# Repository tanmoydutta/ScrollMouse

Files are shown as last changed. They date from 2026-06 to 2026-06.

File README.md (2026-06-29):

# Scroll Mouse using manetic angle sensor
A BLE mouse dial for smooth and minimum effort scrolling. 

Powered by nRF52840 BLE Soc, this HID input device is to reduce effort in scrolling. 

## Demo

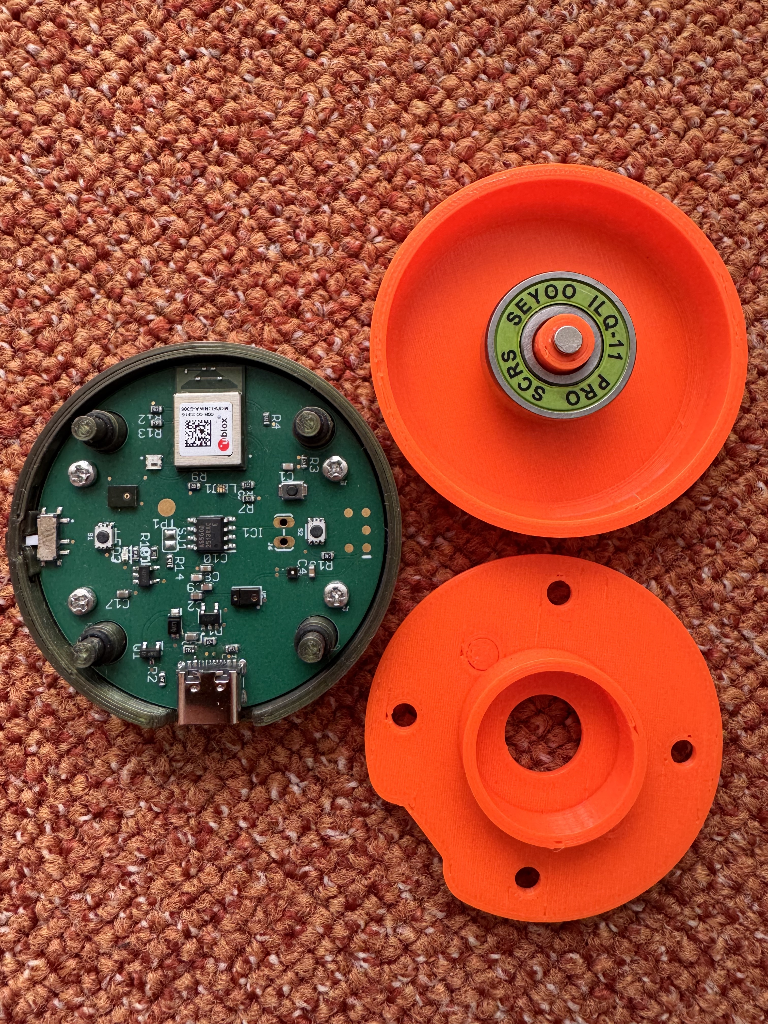
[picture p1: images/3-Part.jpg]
Watch the Scroll Mouse demo


_Click the image to watch the video._

Here is an open view of the device - 


Here is a complete 3D view of the device - 
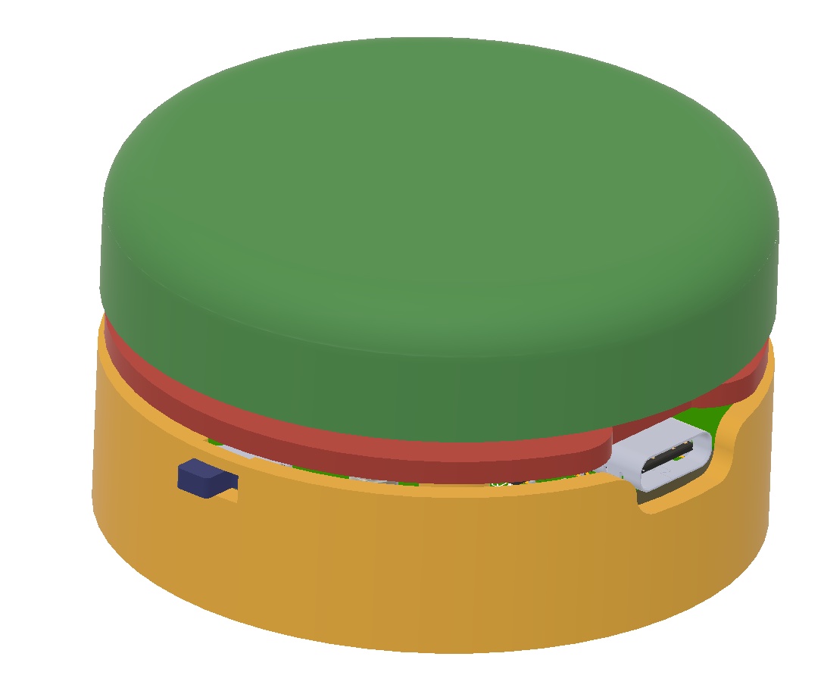
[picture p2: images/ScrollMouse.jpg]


The PCB is designed around AS5600 mangetic engle encoder- 
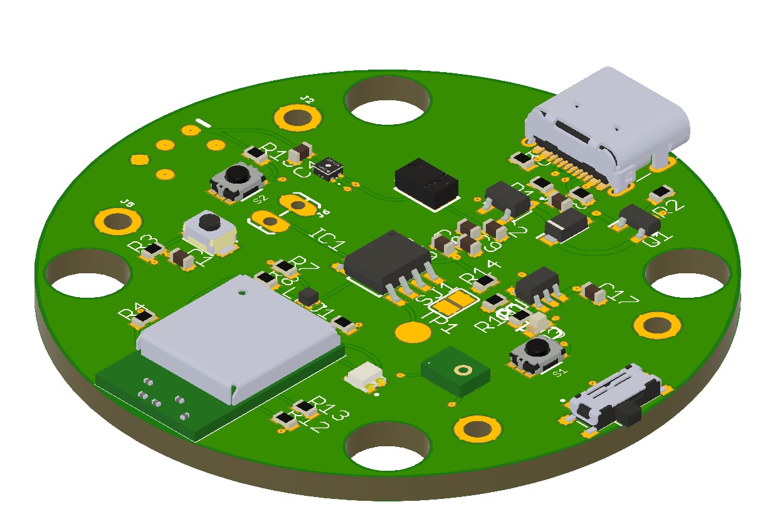
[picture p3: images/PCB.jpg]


In the center is a 608 2RS Bearing for long boards making the swivel action smooth and long running -
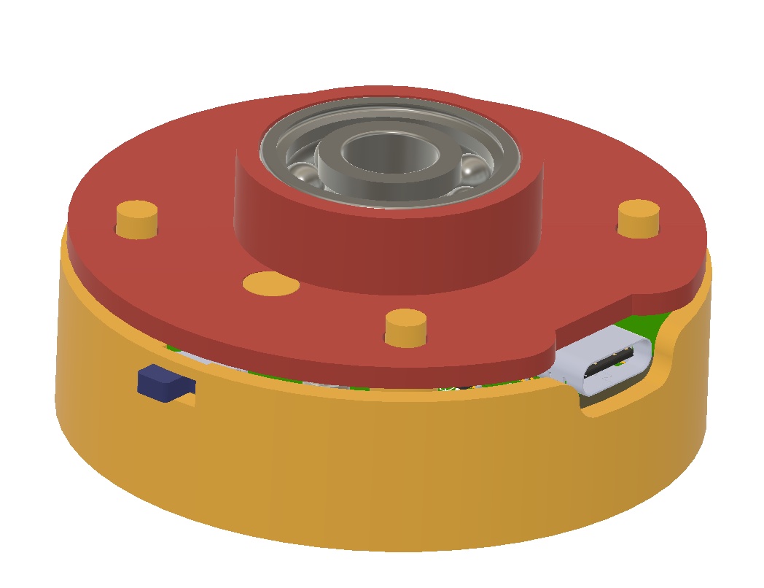
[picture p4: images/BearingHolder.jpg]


The radial magnet in the center of the bearing floats on top of the AS5600 sensor chip to detect the angle of rotation -
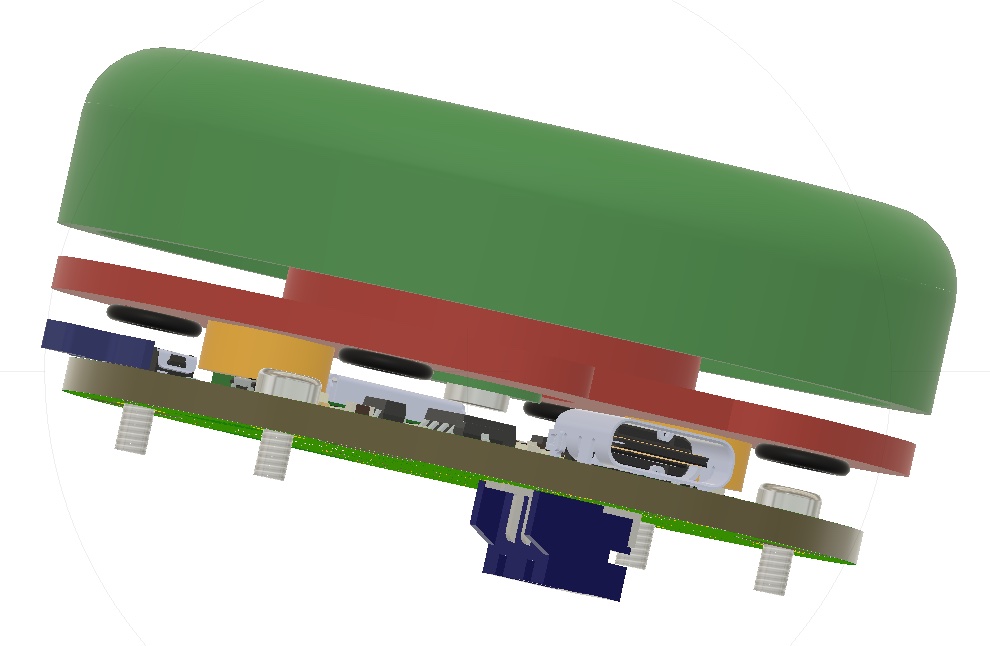
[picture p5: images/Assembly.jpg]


The diametrically magnetised permanent magnet sits in the center of the dial assembly - 
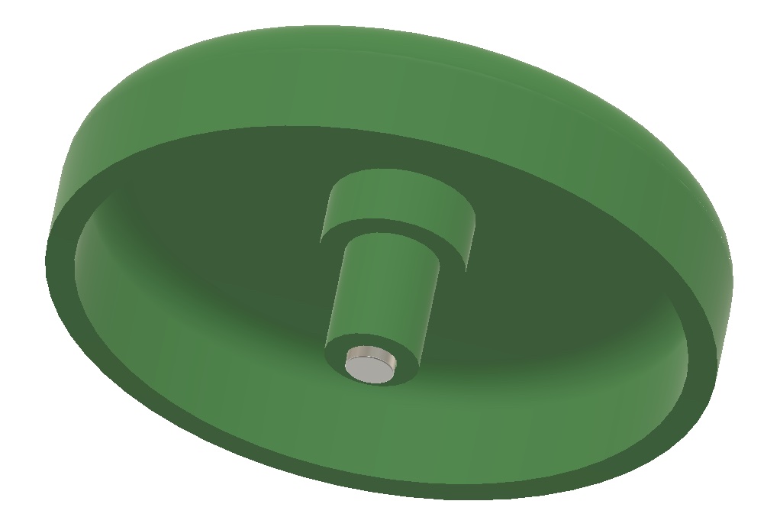
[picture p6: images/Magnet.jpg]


This project is certified as Open Source Hardware - 
<p align="center">
  <a href="https://certification.oshwa.org/nl000044.html">
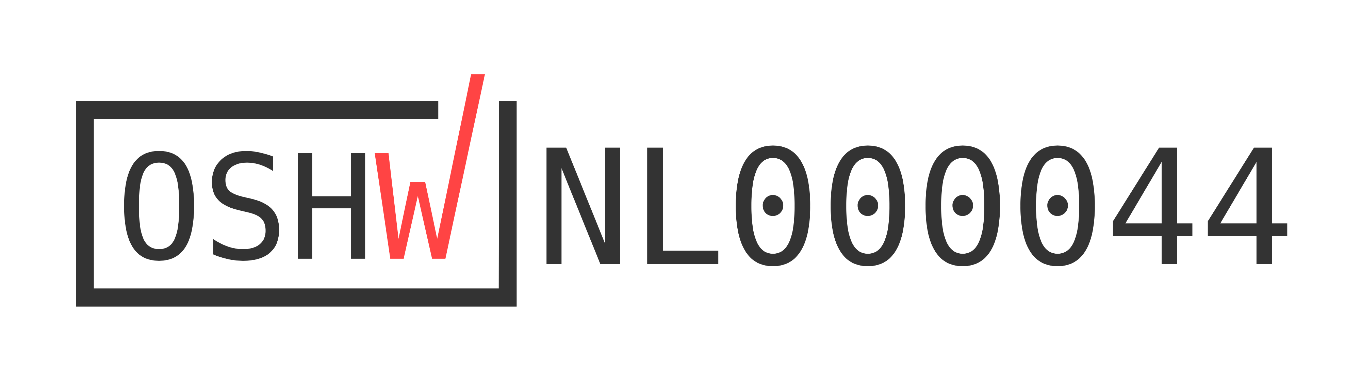
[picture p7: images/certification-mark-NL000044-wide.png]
OSHWA OSHWA Certification
    
  </a>
</p>



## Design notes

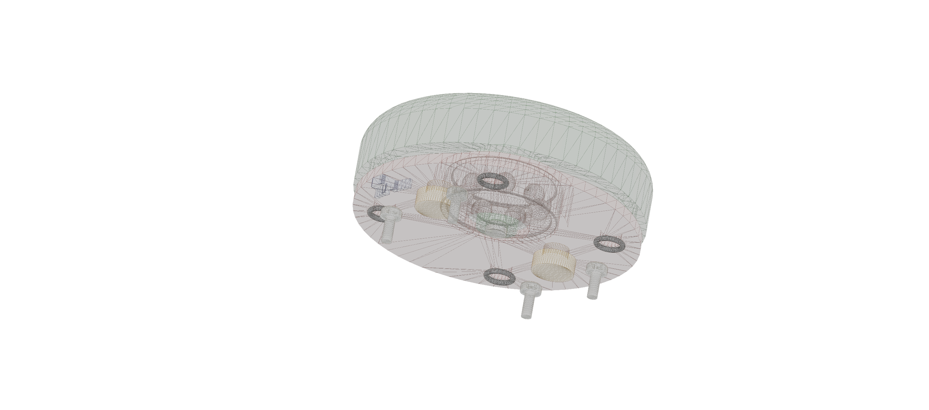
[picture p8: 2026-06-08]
images/ScrollMouseMechanical.png

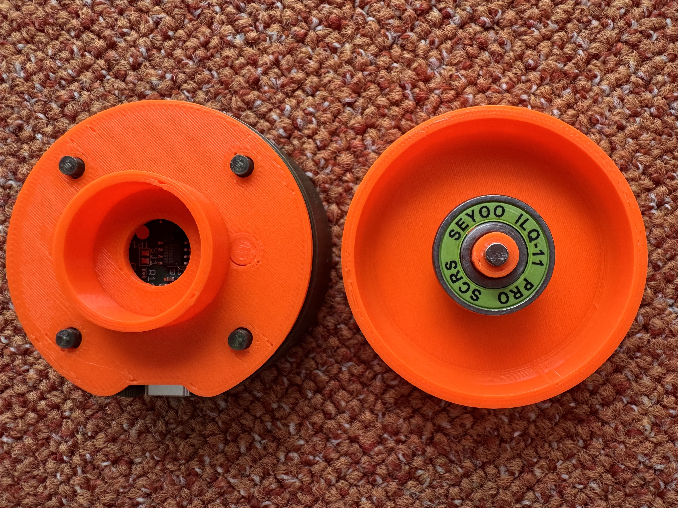
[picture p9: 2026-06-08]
images/2-Part.jpg

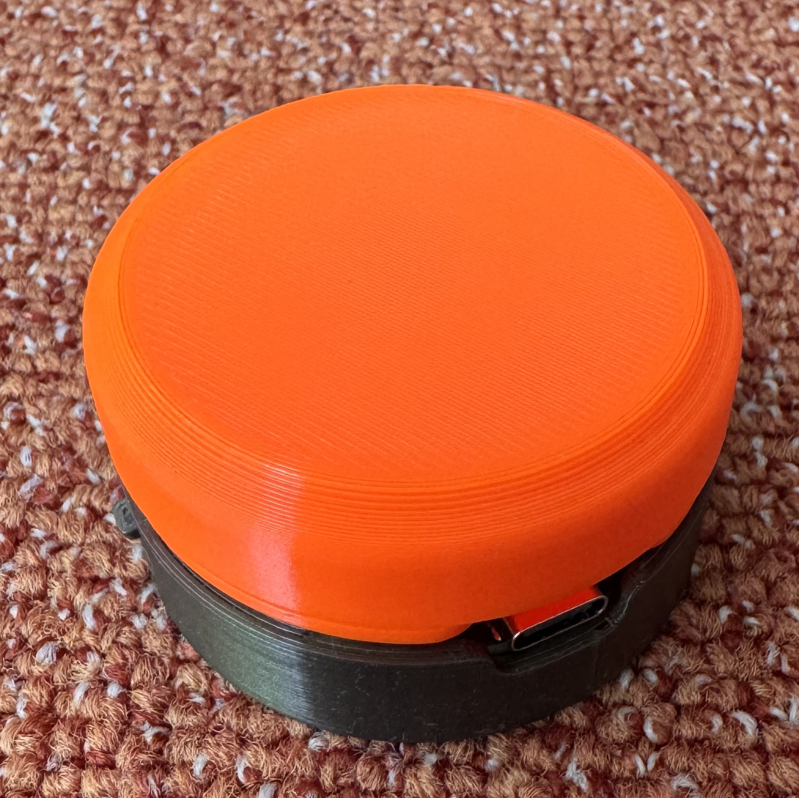
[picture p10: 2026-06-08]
images/Burger.jpg

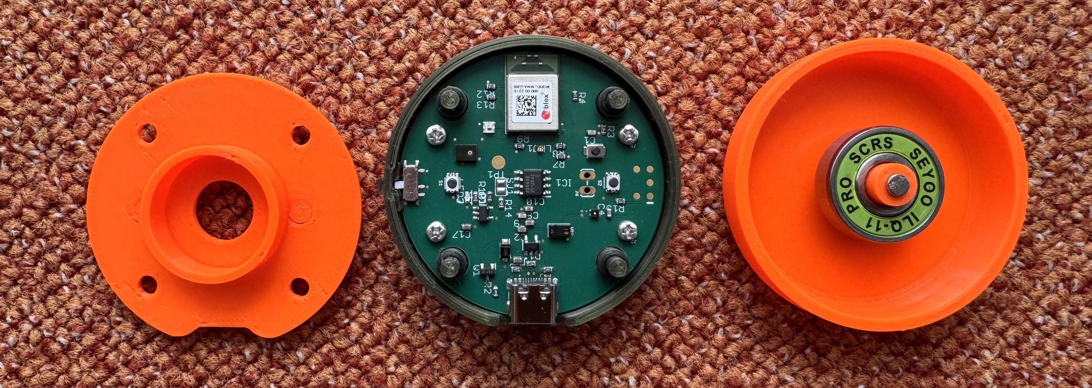
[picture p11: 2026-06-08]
images/Stator-Rotor-Holder-Sensor.jpg

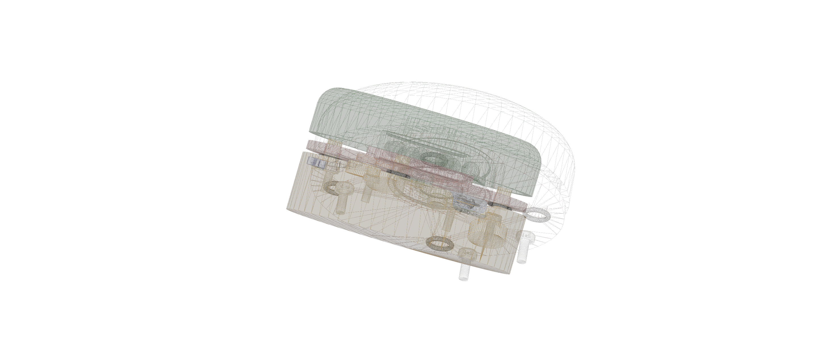
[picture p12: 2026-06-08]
images/ScrollMouse3D.png

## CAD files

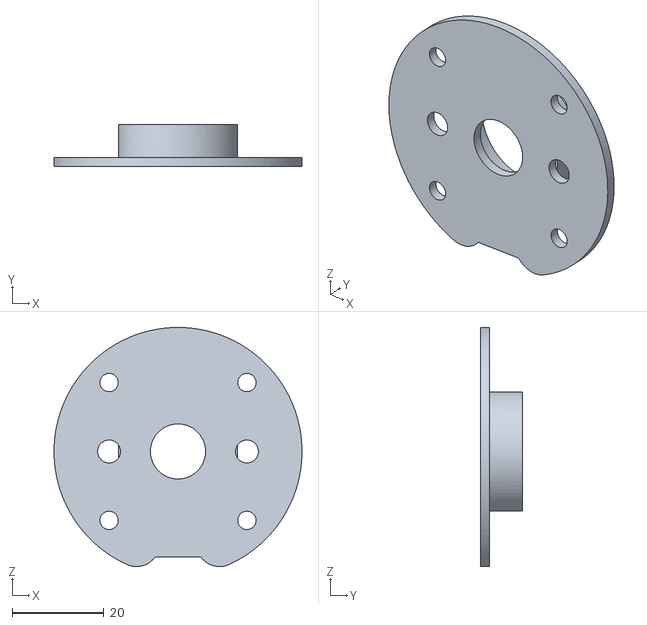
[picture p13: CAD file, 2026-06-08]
3D/BearingHolder.stl
54.0 x 9.20 x 52.1

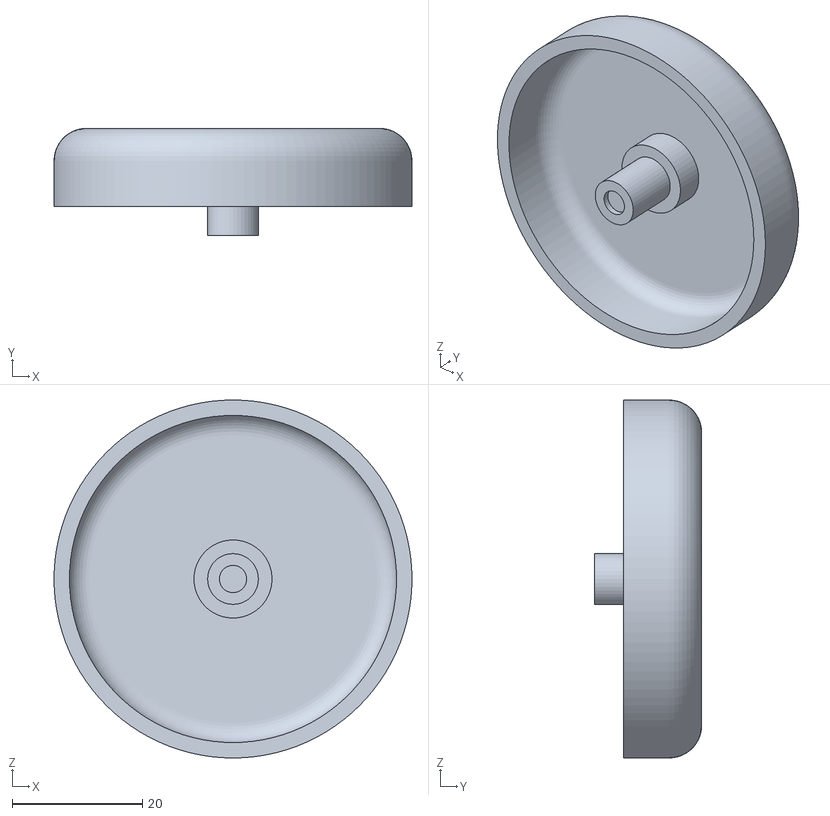
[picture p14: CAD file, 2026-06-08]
3D/RotaryDial.stl
55.0 x 16.5 x 55.0

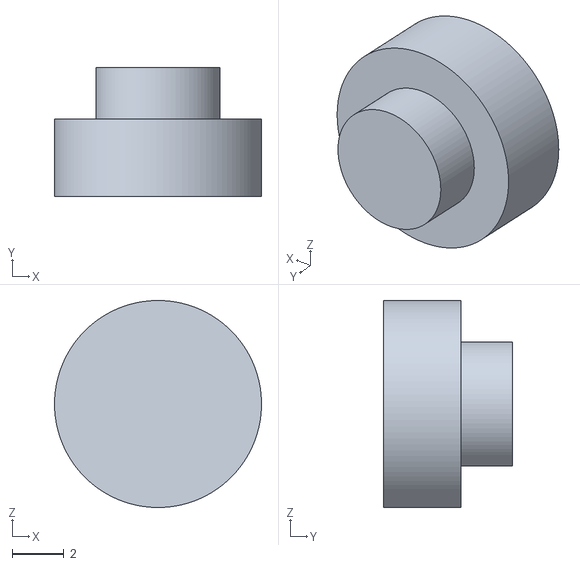
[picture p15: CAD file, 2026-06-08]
3D/ClickBumper.stl
8.00 x 5.00 x 8.00

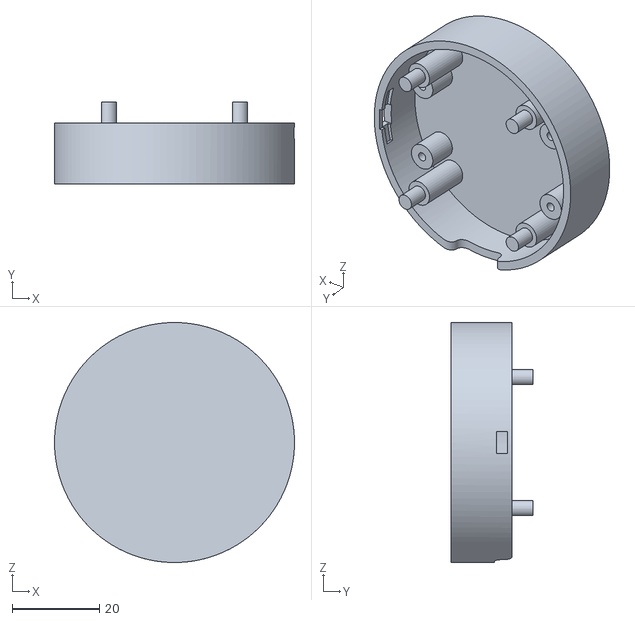
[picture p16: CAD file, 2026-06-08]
3D/SpondeBase.stl
55.0 x 18.9 x 55.0

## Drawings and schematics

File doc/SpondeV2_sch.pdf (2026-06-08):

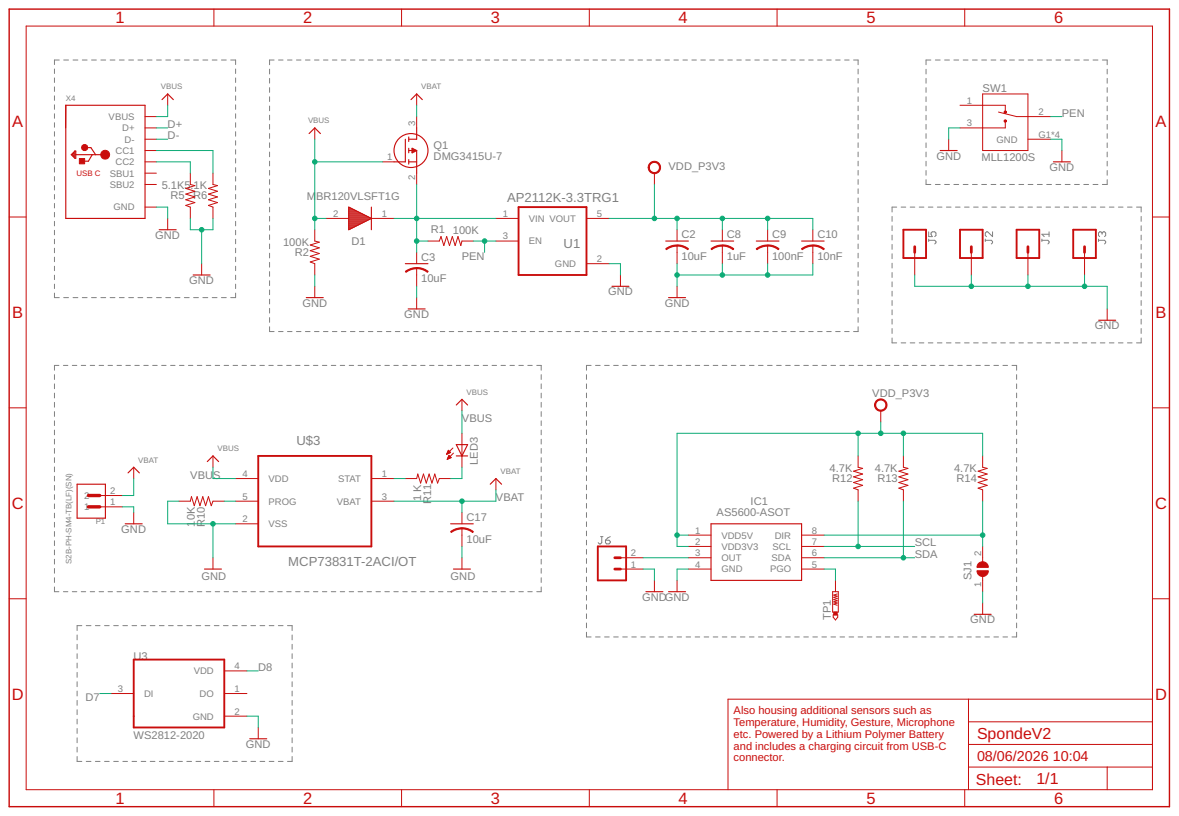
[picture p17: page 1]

VBAT

7 SDA | GND

Also housing additional sensors such as Temperature, Humidity, Gesture, Microphone etc. Powered by a Lithium Polymer Battery and includes a charging circuit from USB-C connector.

Sheet: 1/1

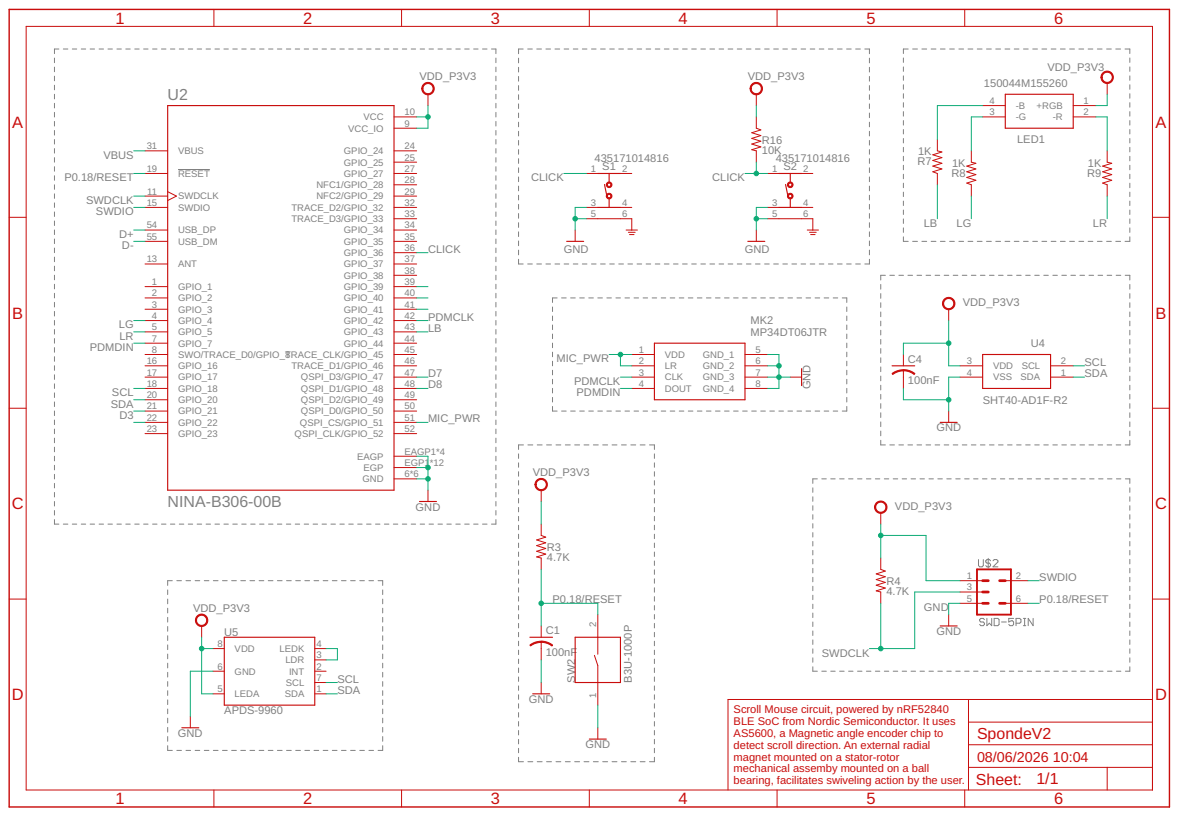
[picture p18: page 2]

Scroll Mouse circuit, powered by nRF52840 BLE SoC from Nordic Semiconductor. It uses AS5600, a Magnetic angle encoder chip to detect scroll direction. An external radial magnet mounted on a stator-rotor mechanical assemby mounted on a ball bearing, facilitates swiveling action by the user.

Sheet: 1/1

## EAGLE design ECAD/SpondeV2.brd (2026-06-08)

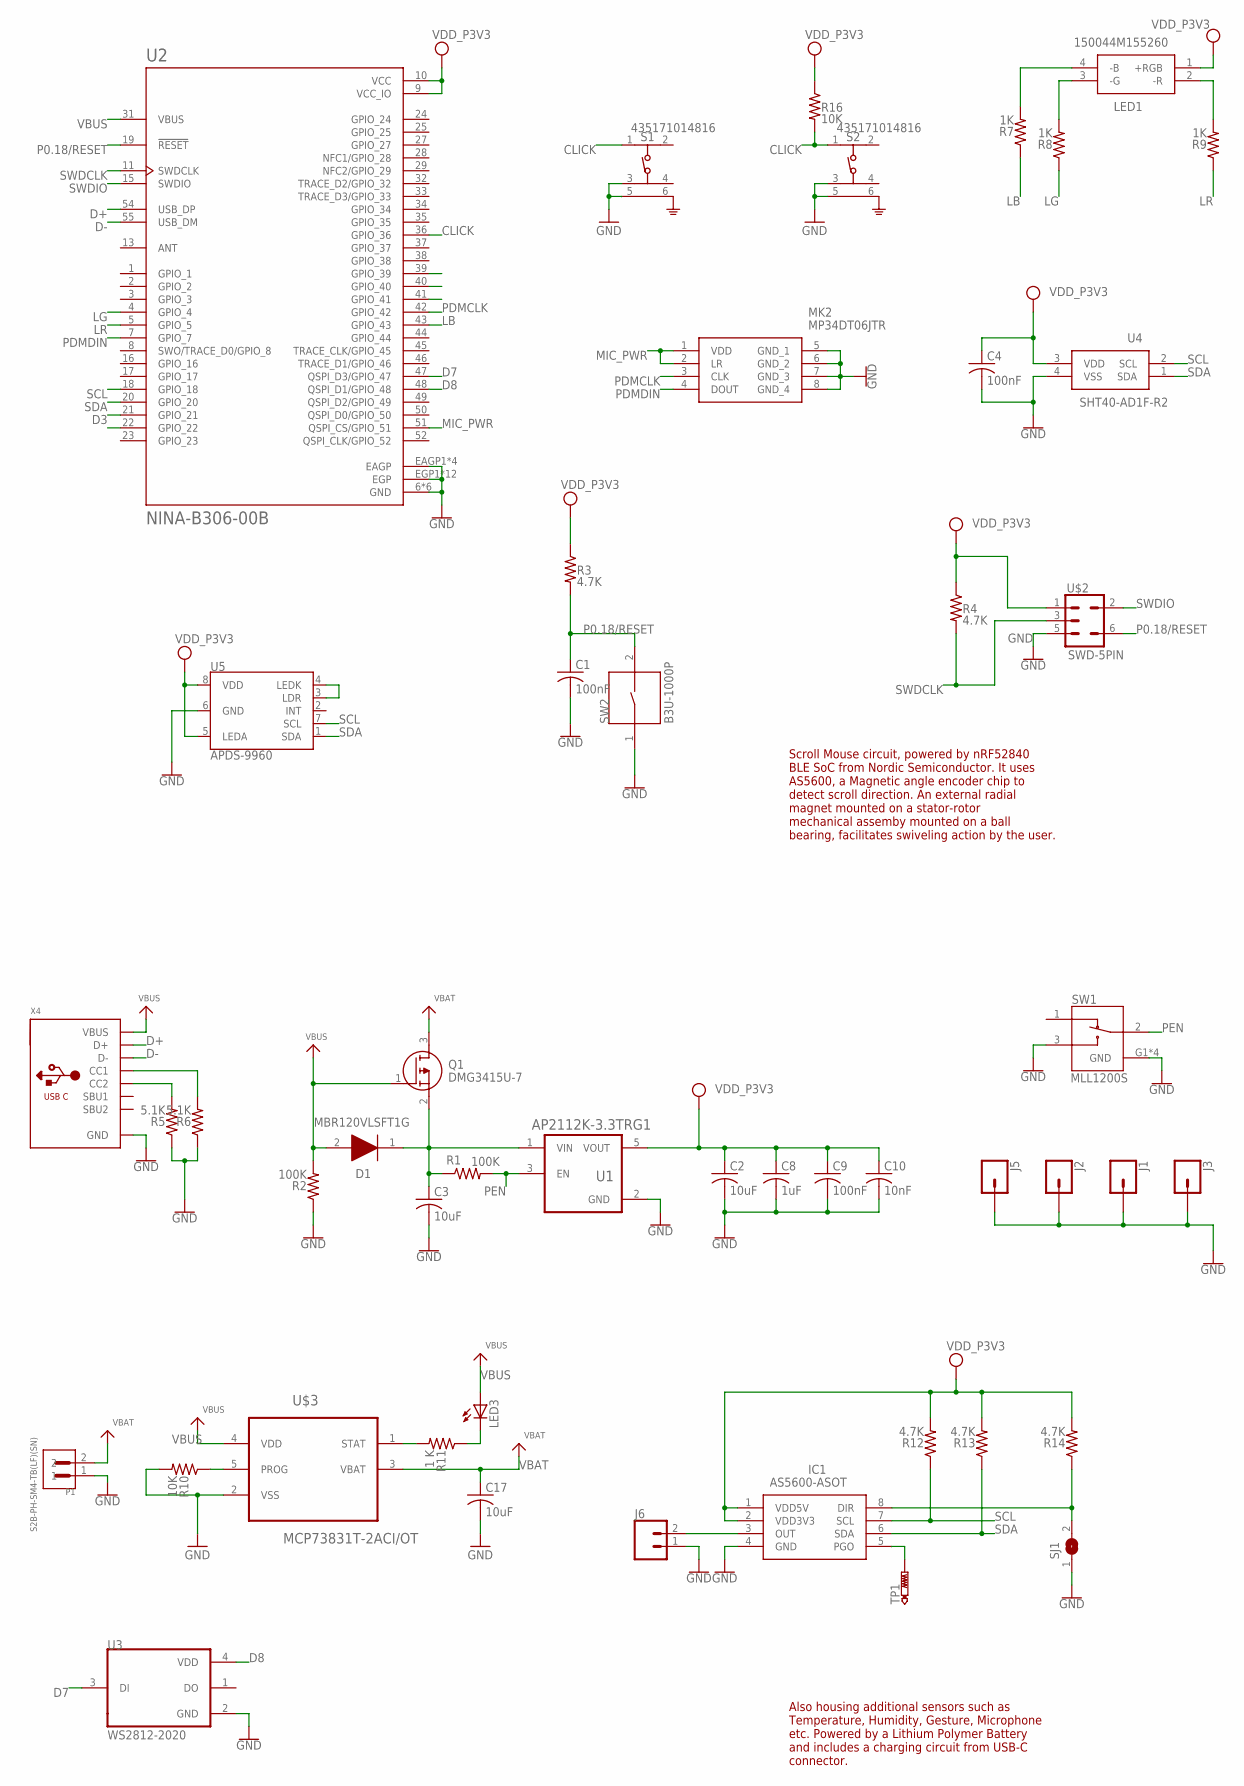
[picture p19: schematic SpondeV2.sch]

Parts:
C1, C4, C9: 100nF; C0402
C2, C3, C17: 10uF; C0402
C8: 1uF; C0402
C10: 10nF; C0402
D1: MBR120VLSFT1G; SODFL3616X98N
IC1: AS5600-ASOT; SOIC127P600X175-8N
J1, J2, J3, J5: CONN_01PTH_2MM; 1X01_2MM
J6: CONN_02LOCK_LONGPADS; 1X02_LOCK_LONGPADS
LED1: 150044M155260
LED3: LEDCHIPLED_0603; CHIPLED_0603
MK2: MP34DT06JTR
P1: S2B-PH-SM4-TB(LF)(SN); JST_S2B-PH-SM4-TB(LF)(SN)
Q1: DMG3415U-7; SOT96P240X100-3N
R1, R2: 100K; R0402
R3, R4, R12, R13, R14: 4.7K; R0402
R5, R6: 5.1K; R0402
R7, R8, R9: 1K; R0402
R10, R16: 10K; R0402
R11: 1 K; R0402
S1, S2: 435171014816
SJ1: SJ
SW1: MLL1200S; SW_MLL1200S
SW2: B3U-1000P; SW_B3U-1000P
TP1: PTR1B2,54; B2,54
U1: AP2112K-3.3TRG1; SOT95P285X140-5N
U2: NINA-B306-00B; XCVR_NINA-B306-00B
U3: WS2812-2020; LED_WS2812-2020
U4: SHT40-AD1F-R2; SHT40AD1FR2
U5: APDS-9960
U$2: SWD-5PIN; PAD_05_03X2_TP_NO4
U$3: MCP73831T-2ACI/OT; SOT95P280X145-5N
X4: MICROBUILDER_USB_C; MICROBUILDER_USB_C_CUSB31-CFM2AX-01-X

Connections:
CLICK: R16.2, S1.1, S2.1, U2.36 (GPIO_36)
D3: U2.21 (GPIO_21)
D7: U2.47 (QSPI_D3/GPIO_47), U3.3 (DI)
D8: U2.48 (QSPI_D1/GPIO_48), U3.4 (VDD)
D+: U2.54 (USB_DP), X4.A6 (D+), X4.B6 (D+)
D-: U2.55 (USB_DM), X4.A7 (D-), X4.B7 (D-)
GND: C1.2, C2.2, C3.2, C4.2, C8.2, C9.2, C10.2, C17.2, IC1.4 (GND), J1.1, J2.1, J3.1, J5.1, J6.1, MK2.5 (GND_1), MK2.6 (GND_2), MK2.7 (GND_3), MK2.8 (GND_4), P1.1, R2.1, R5.1, R6.1, R10.2, S1.3, S1.5, S2.3, S2.5, SJ1.1, SW1.3, SW1.G1 (GND), SW1.G2 (GND), SW1.G3 (GND), SW1.G4 (GND), SW2.1, U1.2 (GND), U2.6 (GND), U2.12 (GND), U2.14 (GND), U2.26 (GND), U2.30 (GND), U2.53 (GND), U2.EAGP1 (EAGP), U2.EAGP2 (EAGP), U2.EAGP3 (EAGP), U2.EAGP4 (EAGP), U2.EGP1 (EGP), U2.EGP2 (EGP), U2.EGP3 (EGP), U2.EGP4 (EGP), U2.EGP5 (EGP), U2.EGP6 (EGP), U2.EGP7 (EGP), U2.EGP8 (EGP), U2.EGP9 (EGP), U2.EGP10 (EGP), U2.EGP11 (EGP), U2.EGP12 (EGP), U3.2 (GND), U4.4 (VSS), U5.6 (GND), U$2.5, U$3.2 (VSS), X4.A1B12 (GND), X4.B1A12 (GND)
LB: R7.1, U2.43 (GPIO_43)
LG: R8.1, U2.4 (GPIO_4)
LR: R9.1, U2.5 (GPIO_5)
MIC_PWR: MK2.1 (VDD), MK2.2 (LR), U2.51 (QSPI_CS/GPIO_51)
unnamed: IC1.5 (PGO), TP1.TP
unnamed: R11.2, U$3.1 (STAT)
unnamed: R5.2, X4.B5 (CC2)
unnamed: R6.2, X4.A5 (CC1)
unnamed: C3.1, D1.1 (K), Q1.2 (S), R1.1, U1.1 (VIN)
unnamed: U5.3 (LDR), U5.4 (LEDK)
unnamed: IC1.8 (DIR), R14.1, SJ1.2
unnamed: IC1.3 (OUT), J6.2
unnamed: LED1.4 (-B), R7.2
unnamed: LED1.3 (-G), R8.2
unnamed: R10.1, U$3.5 (PROG)
unnamed: LED3.C, R11.1
unnamed: LED1.2 (-R), R9.2
P0.18/RESET: C1.1, R3.2, SW2.2, U2.19 (!RESET), U$2.6
PDMCLK: MK2.3 (CLK), U2.42 (GPIO_42)
PDMDIN: MK2.4 (DOUT), U2.7 (GPIO_7)
PEN: R1.2, SW1.2, U1.3 (EN)
SCL: IC1.7 (SCL), R12.1, U2.18 (GPIO_18), U4.2 (SCL), U5.7 (SCL)
SDA: IC1.6 (SDA), R13.1, U2.20 (GPIO_20), U4.1 (SDA), U5.1 (SDA)
SWDCLK: R4.2, U2.11 (SWDCLK), U$2.3
SWDIO: U2.15 (SWDIO), U$2.2
VBAT: C17.1, P1.2, Q1.3 (D), U$3.3 (VBAT)
VBUS: D1.2 (A), LED3.A, Q1.1 (G), R2.2, U2.31 (VBUS), U$3.4 (VDD), X4.A4B9 (VBUS), X4.B4A9 (VBUS)
VCC: C2.1, C4.1, C8.1, C9.1, C10.1, IC1.1 (VDD5V), IC1.2 (VDD3V3), LED1.1 (+RGB), R3.1, R4.1, R12.2, R13.2, R14.2, R16.1, U1.5 (VOUT), U2.9 (VCC_IO), U2.10 (VCC), U4.3 (VDD), U5.5 (LEDA), U5.8 (VDD), U$2.1

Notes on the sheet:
Scroll Mouse circuit, powered by nRF52840 BLE SoC from Nordic Semiconductor. It uses AS5600, a Magnetic angle encoder chip to detect scroll direction. An external radial magnet mounted on a stator-rotor mechanical assemby mounted on a ball bearing, facilitates swiveling action by the user.
Also housing additional sensors such as Temperature, Humidity, Gesture, Microphone etc. Powered by a Lithium Polymer Battery and includes a charging circuit from USB-C connector.

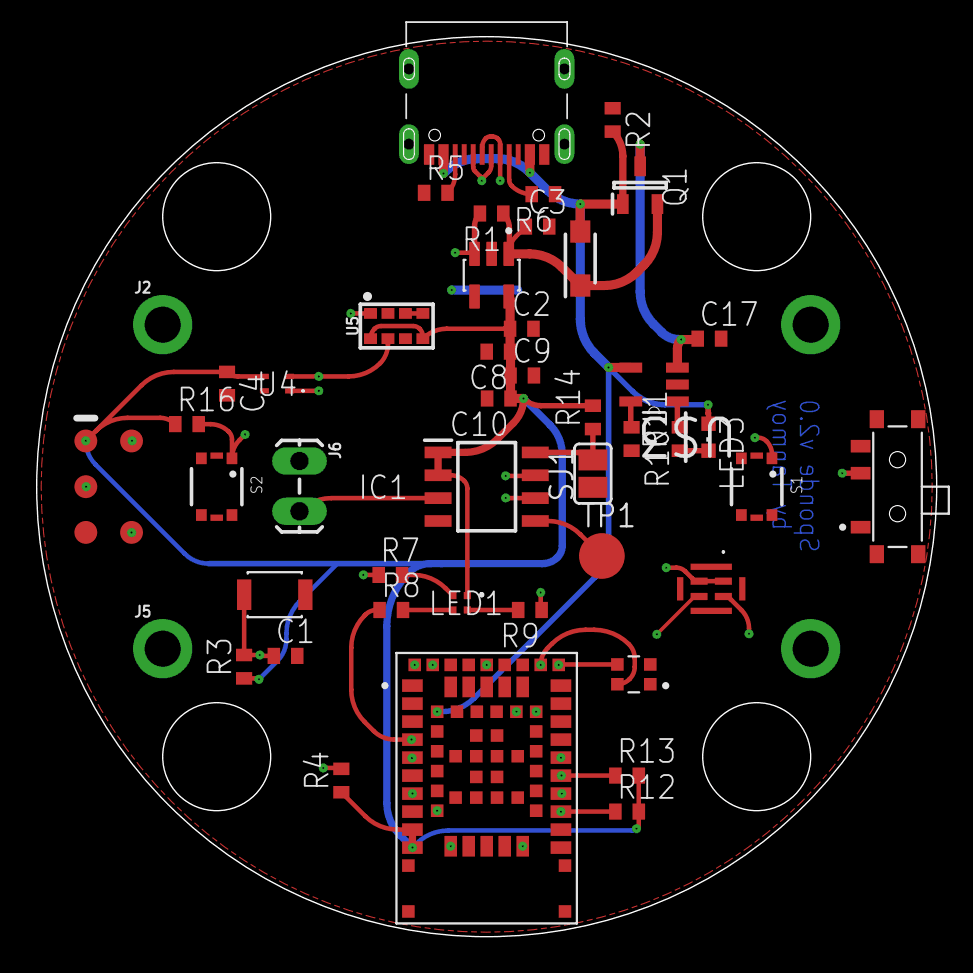
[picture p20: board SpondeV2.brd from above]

Board: 6 copper layers, 50.0 x 50.0 mm, 49 parts (1 on the bottom side), 34 nets.

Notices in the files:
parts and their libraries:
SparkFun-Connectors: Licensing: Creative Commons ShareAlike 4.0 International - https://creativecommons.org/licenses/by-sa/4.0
